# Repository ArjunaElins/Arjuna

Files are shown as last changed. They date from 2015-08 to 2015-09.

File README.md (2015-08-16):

ARJUNA
======

Arjuna is an ODROID based piano learning device. It is created to help the visually impaired to learn to play piano. With Arjuna, we hope to open them a new window to the beautiful world of music.

## Hardware

Arjuna has two main parts, the MPU (MIDI Processing Unit) and the Hands Module.
Here’s the components for both parts:

#### MIDI Processing Unit

1. [ODROID-C1](http://www.hardkernel.com/main/products/prdt_info.php?g_code=G141578608433)
2. nRF24L01+ Transceiver Module
3. Keypad

#### Hands Module

1. [Arduino Pro Micro](https://www.sparkfun.com/products/12640)
2. nRF24L01+ Transceiver Module
3. Small Vibration Motor
4. 1 Cell LiPo Battery
5. 5V Step-up Voltage Regulator
6. 3D Printed Ring
7. 3D Printed Case

## Documentation

* [Components](https://github.com/ArjunaElins/Arjuna/blob/master/Docs/Components.md)
* [Assembly Guide](https://github.com/ArjunaElins/Arjuna/blob/master/Docs/Assembly.md)
* [Installation Guide](https://github.com/ArjunaElins/Arjuna/blob/master/Docs/Installation.md)
* [How It Works](https://github.com/ArjunaElins/Arjuna/blob/master/Docs/HowItWorks.md)
* [About The Project](https://github.com/ArjunaElins/Arjuna/blob/master/Docs/About.md)

## Developer

Arjuna is developed by a three person team from Gadjah Mada University, Indonesia.

* Ilham Imaduddin
* Ahmad Shalahuddin
* Piquitha Della Audyna

## License

This project is licensed under the terms of the [MIT License](http://opensource.org/licenses/MIT).

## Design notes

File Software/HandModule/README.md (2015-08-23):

Hand Module
===========

This is the source code of Arjuna's Hand Module.

## Installation

1. Install [Arduino Pro Micro](https://learn.sparkfun.com/tutorials/pro-micro--fio-v3-hookup-guide) hardware support
2. Add [RF24](https://github.com/stanleyseow/RF24) library to your Arduino IDE
3. Compile and upload ```HandModule.ino```

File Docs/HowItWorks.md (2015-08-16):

How Arjuna Works
================

Arjuna communicates with keyboards by using MIDI (Musical Instrument Digital Interface) protocol, a protocol which enables digital musical instruments, computers, and other supported devices to communicate with each other. With this protocol, MPU can receive data such as notes and velocity from the keyboard while the student is playing.

## The Two Modes

Arjuna has two modes of operation, the *Listen* and the *Evaluation* mode. Both modes require two sets of data, one for song and one for fingering data. Songs are stored in MIDI file (.mid), so you can get it from anywhere on the internet, or you can even make your own song with any MIDI song creator (there are a lot out there). Fingering data can be created from the song file with a software we called MidiFGR. In this software, you can manually set the correct finger to play for each notes, and then it will generate a new file. This file is needed to guide the student to play the correct key with the correct finger.

#### Listen Mode

On Listen mode, MPU will read the chosen song and tell the keyboard to play that song. On the same time, the MPU will send commands to the hand modules, and it will vibrate the correct finger for every notes that should be played. This way, the student can learn the proper fingering skill.

#### Evaluation Mode

On Evaluation mode, the student can play the keyboard and receive the guidance. While the student is playing, the MPU evaluates data received from the keyboard by comparing it with the song file. Once the student made a mistake, MPU will detect it and a command will be given to the hand module. Then the hand module will vibrate the motor on the left side or the right side of the correct finger, depending on the position of the key that should be pressed relative to the wrong pressed key. If the correct key is located to the right of the wrong pressed key, the left motor will vibrate. On the other hand, if the correct key is located to the left of the wrong pressed key, the right motor will vibrate. Of course this behavior can be reversed on the MPU settings.

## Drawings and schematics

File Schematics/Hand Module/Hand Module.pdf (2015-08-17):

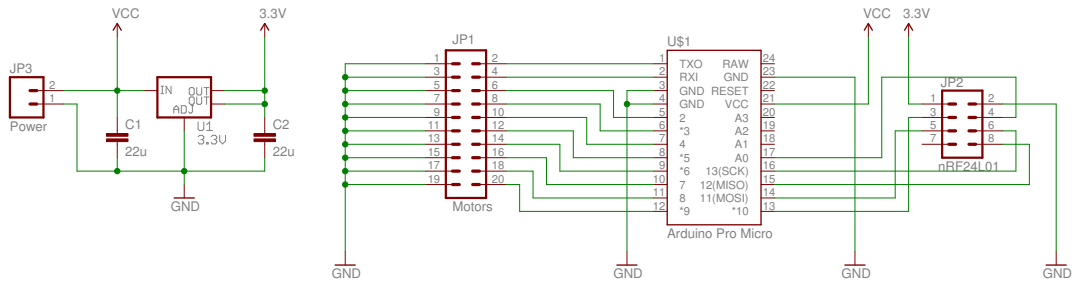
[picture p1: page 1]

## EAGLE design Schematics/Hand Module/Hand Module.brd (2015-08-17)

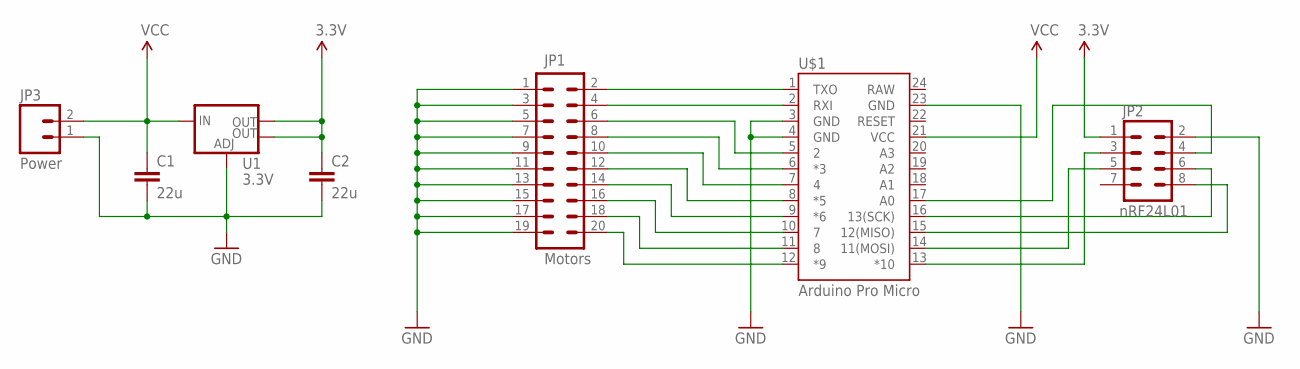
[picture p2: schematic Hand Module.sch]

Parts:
C1, C2: 22u; 0805
JP1: Motors; 2X10
JP2: nRF24L01; 2X4
JP3: Power; 1X02
U1: 3.3V; SOT223
U$1: Arduino Pro Micro; ARDUINO_PRO_MICRO

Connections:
1: JP1.2, U$1.1 (TXO)
2: JP1.4, U$1.2 (RXI)
3: JP1.6, U$1.5 (2)
3.3V: C2.1, JP2.1, U1.2 (OUT), U1.4 (OUT)
4: JP1.8, U$1.6 (*3)
5: JP1.10, U$1.7 (4)
6: JP1.12, U$1.8 (*5)
7: JP1.14, U$1.9 (*6)
8: JP1.16, U$1.10 (7)
9: JP1.18, U$1.11 (8)
10: JP1.20, U$1.12 (*9)
GND: C1.2, C2.2, JP1.1, JP1.3, JP1.5, JP1.7, JP1.9, JP1.11, JP1.13, JP1.15, JP1.17, JP1.19, JP2.2, JP3.1, U1.1 (ADJ), U$1.3 (GND), U$1.4 (GND), U$1.23 (GND)
MISO: JP2.8, U$1.15 (12(MISO))
MOSI: JP2.5, U$1.14 (11(MOSI))
unnamed: JP2.3, U$1.13 (*10)
unnamed: JP2.4, U$1.17 (A0)
SCK: JP2.6, U$1.16 (13(SCK))
VCC: C1.1, JP3.2, U1.3 (IN), U$1.21 (VCC)

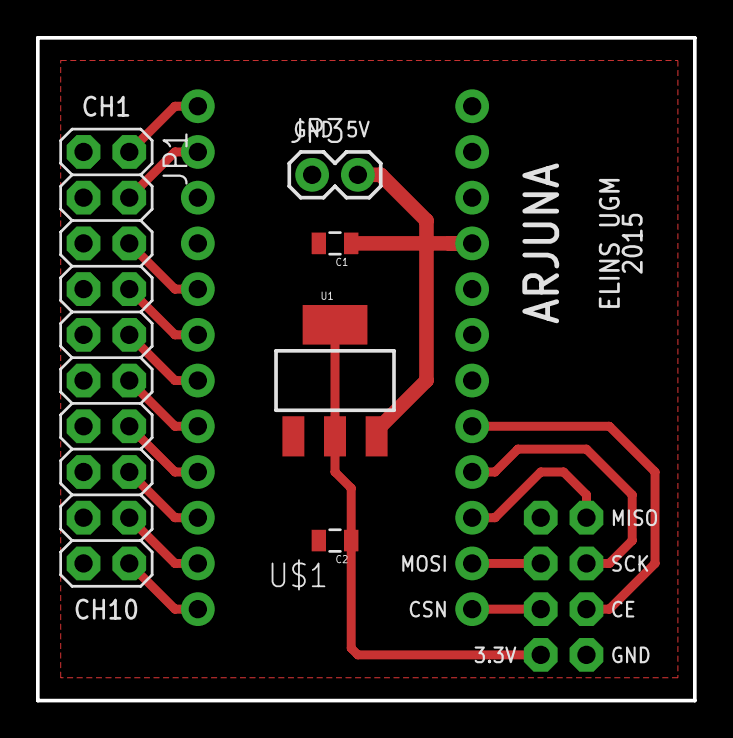
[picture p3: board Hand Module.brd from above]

Board: 2 copper layers, 36.5 x 36.8 mm, 7 parts (1 on the bottom side), 18 nets.

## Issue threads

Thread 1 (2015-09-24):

Force Close on Left Hand Evaluator

ilhamadun, 2015-09-24:
Sometimes the application is crashed after left hand evaluator is finished, probably because of some part of the evaluator tried to access unallocated MIDI or finger data structure.

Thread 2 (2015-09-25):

Adapt Keypad Driver With New Keypad

ilhamadun, 2015-09-25:
Today, we changed the MPU's keypad. Unfortunately its not compatible with the old driver. A deeper investigations will be done.

Closed 2015-10-03.

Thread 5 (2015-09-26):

Evaluator Feedback Only Vibrate on Right Vibrator

ilhamadun, 2015-09-26:
The feedback for evaluator don't have an algorithm to decide which vibrator (left or right) to turn on.

This is a piece of the old-but-working evaluator feedback decision:
```
if (note > in)
		payload = 0x90 | (finger * 2 - 1);
	else
		payload = 0x90 | (finger * 2 - 2);
```

Closed 2015-09-26.

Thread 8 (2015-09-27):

Imprecise Note Interval

ilhamadun, 2015-09-27:
For an unknown reason, the note interval delay is imprecise. Sometime its too slow and sometime its to fast. And in some case, several notes in the beginning is grouped and played simultaneously.

Maybe the problem is WiringPi's ```DelayMicroseconds(unsigned int)``` function. We should try to change it to native Linux's high resolution timing method, ```nanosleep(const struct timespec*, struc timespec*)``` and see if it performs better.

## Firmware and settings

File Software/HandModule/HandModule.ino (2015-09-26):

/**
 * Arjuna Hand Module
 *
 * Copyright (c) 2015 Arjuna
 *
 * Developed by:
 *   Ilham Imaduddin
 *   Piquitha Della Audyna
 * 
 *   Gadjah Mada University
 *
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
 * THE SOFTWARE IS PROVIDED "AS IS", WITHOUT WARRANTY OF ANY KIND, EXPRESS OR
 * IMPLIED, INCLUDING BUT NOT LIMITED TO THE WARRANTIES OF MERCHANTABILITY,
 * FITNESS FOR A PARTICULAR PURPOSE AND NONINFRINGEMENT. IN NO EVENT SHALL THE
 * AUTHORS OR COPYRIGHT HOLDERS BE LIABLE FOR ANY CLAIM, DAMAGES OR OTHER
 * LIABILITY, WHETHER IN AN ACTION OF CONTRACT, TORT OR OTHERWISE, ARISING FROM,
 * OUT OF OR IN CONNECTION WITH THE SOFTWARE OR THE USE OR OTHER DEALINGS IN
 * THE SOFTWARE.
 */
 
#include <SPI.h>
#include <RF24.h>
#include <printf.h>

#define RIGHT_HAND  "ArS01"
#define LEFT_HAND   "ArS02"
#define ADDRESS     RIGHT_HAND

class Motor
{
  enum MotorStatus{OFF, ON};
  const int TIMEOUT = 500;
  
  private:
    bool status;
    int pin;
    unsigned long activeOn;

  public:
    /**
     * Initialize Motor
     * 
     * Assign pin number and set it as output
     * 
     * @param pinNumber   Arduino Pin Number
     */
    void init(int pinNumber)
    {
      pin = pinNumber;
      pinMode(pin, OUTPUT);
    }

    /**
     * Turn On Motor
     */
    void turnOn()
    {
      digitalWrite(pin, HIGH);
      status = ON;
      activeOn = millis();
    }

    /**
     * Turn Off Motor
     */
    void turnOff()
    {
      digitalWrite(pin, LOW);
      status = OFF;
      activeOn = 0;
    }

    /**
     * Get Motor Status
     * 
     * @return  MotorStatus
     */
    bool getStatus()
    {
      return status;
    }

    /**
     * Control Motor Timeout
     */
    void timeoutControl()
    {
      if ((millis() - activeOn) > TIMEOUT)
      {
        turnOff();
      }
    }
};

#define MOTOR_COUNT     10
#define MOTOR_OFF       0x80
#define MOTOR_ON        0x90
#define ALL_MOTOR_OFF   0xC0
#define ALL_MOTOR_ON    0xD0

RF24 radio(19, 10);
byte data;
Motor motor[MOTOR_COUNT];
int motorPin[MOTOR_COUNT] = {1, 0, 2, 3, 4, 5, 6, 7, 8, 9};

void setup()
{
  /* Initialize RF Address */
  byte address[6] = ADDRESS;

  /* Initialize serial communication */
  Serial.begin(9600);
  printf_begin();

  /* Initialize radio */
  Serial.println("Initializing radio...");
  radio.begin();
  radio.setPALevel(RF24_PA_LOW);
  radio.setPayloadSize(1);
  radio.setAutoAck(1);
  radio.openReadingPipe(1, address);
  radio.startListening();
  radio.printDetails();
  Serial.println("Radio is listening...");

  // Initializing Motor
  for (int i = 0; i < MOTOR_COUNT; i++)
  {
    motor[i].init(motorPin[i]);
  }
  allMotorOff();
}

void loop()
{
  if (radio.available())
  {
    while (radio.available())
    { 
      radio.read(&data, 1);

      Serial.print("Data received: ");
      Serial.println(data, HEX);
      parseCommand(data);
    }
  }

  // Run Motor Timeout Controller
  for (int i = 0; i < MOTOR_COUNT; i++)
  {
    motor[i].timeoutControl();
  }
  
}

/**
 * Parse command
 * 
 * @param   message   command message
 */
void parseCommand(byte message)
{
  byte command = message & 0xF0;
  byte channel = message & 0x0F;

  if (channel > MOTOR_COUNT - 1)
    return;

   switch(command)
   {
      case MOTOR_OFF:
        motor[channel].turnOff();
        break;
      case MOTOR_ON:
        motor[channel].turnOn();
        break;
      case ALL_MOTOR_OFF:
        allMotorOff();
        break;
      case ALL_MOTOR_ON:
        allMotorOn(); 
        break;
   }
}

/**
 * Turn Off All Motor
 */
void allMotorOn()
{
  for (int i = 0; i < MOTOR_COUNT; i++)
  {
    motor[i].turnOn();
  }
}

/**
 * Turn Off All Motor
 */
void allMotorOff()
{
  for (int i = 0; i < MOTOR_COUNT; i++)
  {
    motor[i].turnOff();
  }
}

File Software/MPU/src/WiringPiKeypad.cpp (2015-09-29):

/**
 * WiringPi Matrix Keypad Library
 *
 * Copyright (c) 2015 Ilham Imaduddin <ilham.imaduddin@mail.ugm.ac.id>
 *
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
 */

#include "WiringPiKeypad.h"

/**
 * Class constructor
 */
WiringPiKeypad::WiringPiKeypad(int _rowSize, int _columnSize)
: rowSize(_rowSize), columnSize(_columnSize), debounceDelay(200), pollingDelay(20)
{
	rowPin = (int *) malloc(sizeof(int) * rowSize);
	columnPin = (int *) malloc(sizeof(int) * columnSize);
}

/**
 * Class constructor
 */
WiringPiKeypad::WiringPiKeypad(int _rowSize, int _columnSize, int _debounce, int _polling)
: rowSize(_rowSize), columnSize(_columnSize), debounceDelay(_debounce), pollingDelay(_polling)
{
	rowPin = (int *) malloc(sizeof(int) * rowSize);
	columnPin = (int *) malloc(sizeof(int) * columnSize);
}

/**
 * Set row pin
 * 
 * @param 	row 	array with rowSize elements
 */
void WiringPiKeypad::setRowPin(int *row)
{
	for (int i = 0; i < rowSize; i++)
	{
		rowPin[i] = row[i];
	}
}

/**
 * Set column pin
 * 
 * @param 	column 	array with columnSize elements
 */
void WiringPiKeypad::setColumnPin(int *column)
{
	for (int i = 0; i < columnSize; i++)
	{
		columnPin[i] = column[i];
	}
}

/**
 * Set keypad matrix
 * 
 * @param matrix 	keypad matrix
 */
void WiringPiKeypad::setMatrix(std::vector<std::vector<char>> m)
{
	matrix = m;
}

/**
 * Set debounce delay
 * 
 * @param delay 	delay in miliseconds
 */
void WiringPiKeypad::setDebounceDelay(int delay)
{
	debounceDelay = delay;
}

/**
 * Set polling delay
 * 
 * @param delay 	delay in miliseconds
 */
void WiringPiKeypad::setPollingDelay(int delay)
{
	pollingDelay = delay;
}

/**
 * Get debounce delay
 * 
 * @return  delay in miliseconds
 */
int WiringPiKeypad::getDebounceDelay(void)
{
	return debounceDelay;
}

/**
 * Get polling delay
 * 
 * @return  delay in miliseconds
 */
int WiringPiKeypad::getPollingDelay(void)
{
	return pollingDelay;
}

/**
 * Listen to keypress and return raw key data
 * 
 * @return  key structure
 */
struct key WiringPiKeypad::getRawKey(void)
{
	bool terminator = true;
	return getRawKey(&terminator);
}

/**
 * Listen to keypress and return raw key data
 * 
 * @return  key structure
 */
struct key WiringPiKeypad::getRawKey(bool *terminator)
{
	struct key k;

	for (int i = 0; i < columnSize; i++)
	{
		pinMode(columnPin[i], INPUT);
		pullUpDnControl(columnPin[i], PUD_UP);
	}

	for (int i = 0; i < rowSize; i++)
	{
		pinMode(rowPin[i], INPUT);
		pullUpDnControl(rowPin[i], PUD_OFF);
	}

	while (*terminator)
	{
		for (int i = 0; i < rowSize; i++)
		{
			pinMode(rowPin[i], OUTPUT);
			digitalWrite(rowPin[i], LOW);

			for (int j = 0; j < columnSize; j++)
			{
				if (! digitalRead(columnPin[j]))
				{
					delay(debounceDelay);
					k.row = i;
					k.column = j;

					return k;
				}
			}

			pinMode(rowPin[i], INPUT);
			pullUpDnControl(rowPin[i], PUD_OFF);

			delay(pollingDelay);
		}
	}

	return k;
}

/**
 * Get keypress and return key data from matrix
 * 
 * @return  pressed key
 */
char WiringPiKeypad::getKey(void)
{
	bool terminator = true;
	struct key k = getRawKey(&terminator);

	return matrix[k.row][k.column];
}

/**
 * Get keypress and return key data from matrix
 * 
 * @return  pressed key
 */
char WiringPiKeypad::getKey(bool *terminator)
{
	struct key k = getRawKey(terminator);

	return matrix[k.row][k.column];
}

/**
 * Check input value
 * 
 * @param  row    	row value to check
 * @param  column 	column value to check
 */
bool WiringPiKeypad::inputIs(int row, int column)
{
	return inputIs(getRawKey(), row, column);
}

/**
 * Check input value
 *
 * @param  key 		keypress
 * @param  row    	row value to check
 * @param  column 	column value to check
 */
bool WiringPiKeypad::inputIs(struct key keypress, int row, int column)
{
	if (keypress.row == row && keypress.column == column)
	{
		return true;
	}
	else
	{
		return false;
	}
}

/**
 * Print setup details
 */
void WiringPiKeypad::printDetails(void)
{
	std::cout << "Row size:\t" << rowSize << std::endl;
	std::cout << "Column size:\t" << rowSize << std::endl;

	std::cout << "Row pin:\t";
	for (int i = 0; i < rowSize; i++)
	{
		std::cout << rowPin[i] << " ";
	}
	std::cout << std::endl;

	std::cout << "Column pin:\t";
	for (int i = 0; i < columnSize; i++)
	{
		std::cout << columnPin[i] << " ";
	}
	std::cout << std::endl;

	std::cout << "Debounce delay:\t" << debounceDelay << std::endl;
	std::cout << "Polling delay:\t" << pollingDelay << std::endl;
}

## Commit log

2015-08-17 Add Hand Module Schematic and Board
    [Hand Module.brd, Hand Module.sch]
2015-08-23 Add Motor Support for Hand Module
2015-08-24 Fix Hand Module Tranceiver
    [HandModule.ino]
2015-09-08 Add WiringPi Initialization
    The WiringPi initialization is part of the hardware initialization. It
    is created first because all other hardware initialization is depending
    on it.
2015-09-09 Fix Method Name Case
    Change some method name case to camelCase for consistent naming.
2015-09-23 Add Button Definition
    Change keypad button from magic value to defined constant
2015-09-23 Add Stopper
    The stopper is a function that called in separate thread to stop the
    player/evaluator in the middle of operation
2015-09-23 Adapt FingerData Class to New MidiFGR Output
    The MidiFGR is changed to produce a simpler file. This commit introduces
    the adaption of FingerData class.
2015-09-23 Dump Unused FingerData Methods
2015-09-24 Groups Unison Finger
    Improves evaluator function by adding getUnisonFinger, a function to
    group finger data played at the same time.
2015-09-24 Adapt Hand Module to New Schematic
    The hand module schematic is revised, this commit adapt the Arduino Pro
    Micro with the new schematic.
2015-09-25 Reset Buttons
    Change button to original functions.
2015-10-03 Fix Keypad Driver
    The new keypad is now working by changing the row. column, and matrix
    values.
    This commit fixes #2 issue.

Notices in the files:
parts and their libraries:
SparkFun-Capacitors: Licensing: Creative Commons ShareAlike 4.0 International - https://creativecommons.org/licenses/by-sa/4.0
